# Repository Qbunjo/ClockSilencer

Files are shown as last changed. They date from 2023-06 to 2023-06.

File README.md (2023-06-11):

# ClockSilencer
ClockSilencer is a simple ESP32 device. It plays recorded chime on certain hours.
## Why do I need that?
The problem is, I've got an antique pendulum clock from 1930s. When it chimes, it chimes all day long, day and night. I just wanted to silence it at night.
My first idea was to build a blocking mechanism inside the clock box, but it turns out to be very difficult and I had some doubts about the clock mechanism.
Much more elegant solution is having another electronic clock, that plays recorded chime on certain hours.

## Hardware:
- ESP32 WROOM
- DFPlayer mini
- micro SD card (a small one will be enough - 8gb or even less)
- MOSFET transistor (it turns out that DFPlayer is power-hungry even if it sleeps, so it's better to cut its power)
- DS3231 RTC 
### Why not use ESP32's internal RTC?
Because it turns out, when in deepsleep, internal RTC becomes inacurrate (like 5 minutes in 12 hours)

## Libraries:
- RTClib - runs DS3231 clock
- HardwareSerial - as DFPlayer is driven by Serial port, second serial must be set.
- DFPlayerMini_Fast - driver for DFPlayer Mini, but not from DFRobot :)
- FireTimer (dependency of DFPlayer library)

## Wiring:
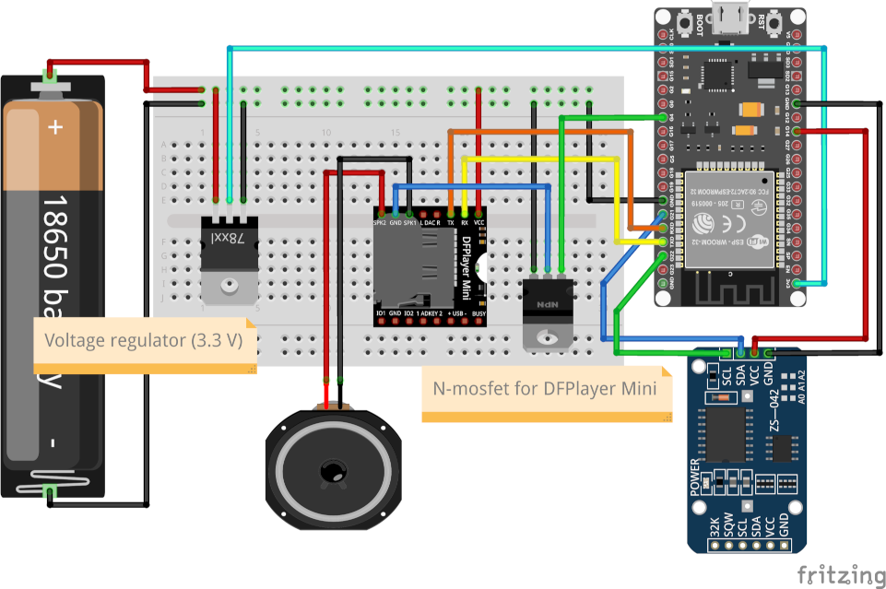
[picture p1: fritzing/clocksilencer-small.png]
Fritzing ESP32 schema


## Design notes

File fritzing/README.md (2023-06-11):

# Fritzing

## Fritzing parts

Please open the parts in this folder to add them into your Fritzing library:

1. [18650 Battery Holder](https://forum.fritzing.org/t/18650-battery-holder-part-design/6523/24)
    - `18650 battery holder_mod.fzpz`
2. [ESP32 Wroom-32U](https://forum.fritzing.org/t/esp32-wroom-32u/12978/2)
    - `ESP32-38PinWide-fixed.fzpz`
3. [DFPlayer Mini](https://fritzing.org/projects/dfplayer-mini-part)
    - `DFPlayer MINI.fzpz`

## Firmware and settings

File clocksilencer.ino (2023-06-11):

#include <DFPlayerMini_Fast.h>
#include <HardwareSerial.h>
//#include <ESP32Time.h> //we quit using this crappy internal RTC
#include <WiFi.h>
#include "RTClib.h"

RTC_DS3231 rtc;
HardwareSerial hwSerial(1);
DFPlayerMini_Fast myDFPlayer;
char daysOfTheWeek[7][12] = { "Sunday", "Monday", "Tuesday", "Wednesday", "Thursday", "Friday", "Saturday" };
const char *ssid = "SSID";
const char *password = "PASS";
RTC_DATA_ATTR bool rtcTimeWasAlreadySetFromNTP = false;
bool noWifi;
int myDow, mySec, myMin, myHour;
int sleepHelper;

void setup() {
  pinMode(4, OUTPUT);
  pinMode(14,OUTPUT);
  //digitalWrite(14, HIGH);//give power to rtc
  Serial.begin(115200);
  hwSerial.begin(9600, SERIAL_8N1, 16, 17);  // second serial port to serve mp3 player
  
  if (rtcTimeWasAlreadySetFromNTP == false) {
    synchroniseExternalTime();
  }
}

void loop() {
  //---this is serial output to make sure we have correct time
  //DateTime now = rtc.now();
  DateTime now =grabTime();
  
  //--- here are regular conditions
  myDow = now.dayOfTheWeek();
  mySec = now.second();
  myMin = now.minute();
  myHour = now.hour();
Serial.print("It is ");
Serial.print(myHour);
Serial.print(":");
Serial.print(myMin);
Serial.print(":");
Serial.println(mySec);


  if (myMin > 31) {
    sleepHelper = 59 - myMin;
  } else {
    sleepHelper = 29 - myMin;
  };
  if (myHour > 7 and myHour < 19 and mySec == 55 and sleepHelper == 0) {  //according to the DFPlayer documentation, it needs 3-5 seconds to start
    startPlayer();
  }

  //---------ringing conditions----------

  if (mySec == 0 and myMin == 0) {     // at full hour
    if (myHour > 7 and myHour < 19) {  // between 8 and 18
      // here another condition
      ringer(myHour);
    }
  }
  if (mySec == 0 and myMin == 30) {    // at half hour
    if (myHour > 7 and myHour < 19) {  // between 8 and 18
      // here another condition
      ringer(1);
    }
  }


  // -----deep sleep conditions--------
  if ((sleepHelper > 2)) {
    deepsleep(sleepHelper);
  }
  delay(1000);  //if there is a short time to chime, just work with delay
}
void ringer(int myhours2) {
  //run mosfet here

  Serial.print("Ringing:");
  Serial.println(myhours2);
  if (myhours2 > 12) {
    myhours2 -= 12;
  }
  for (int n = 1; n <= myhours2; n++) {
    Serial.print("Ring nr:");
    Serial.println(n);
    if (n == 1) {
      myDFPlayer.playFromMP3Folder(1);
      delay(2250);

    }  // ring the chime
    else {
      myDFPlayer.playFromMP3Folder(2);
      delay(2250);
    }
  }
  while (myDFPlayer.isPlaying()) {
  };
  digitalWrite(4, LOW);
  Serial.println("Mosfet low");

}
void deepsleep(int sleepHelper) {
  int countMicro = ((sleepHelper - 1) * 1000000 * 60);
  esp_sleep_enable_timer_wakeup(countMicro);
  Serial.println("Deepsleep");
  Serial.print("Wake up in ");
  Serial.print(sleepHelper);
  Serial.print(" minutes, at ");
  Serial.print(myHour);
  Serial.print(":");
  Serial.println(myMin += sleepHelper);
  esp_deep_sleep_start();
}
void synchroniseExternalTime() {
  WiFi.begin(ssid, password);
  Serial.println("Looking for the WiFi");
  while (WiFi.status() != WL_CONNECTED) {
    delay(500);
    Serial.print(".");
    // if wifi found, break loop
  }
  Serial.println("WiFi connected");
  //---------set with NTP---------------
  // we have to rebuild this function to synchronise ext rtc
  configTime(3600, 3600, "europe.pool.ntp.org");
  //==== //this need to be further modified to meet the requirements of RTClib
  struct tm timeinfo;
  getLocalTime(&timeinfo);

  int yr = timeinfo.tm_year + 1900;
  int mt = timeinfo.tm_mon + 1;
  int dy = timeinfo.tm_mday;
  int hr = timeinfo.tm_hour;
  int mi = timeinfo.tm_min;
  int se = timeinfo.tm_sec;

  digitalWrite(14,HIGH);
  rtc.begin();
  rtc.adjust(DateTime(yr, mt, dy, hr, mi, se));

  Serial.println("RTC updated");
  DateTime now = rtc.now();
  Serial.print("It is ");
  Serial.print(now.year(), DEC);
  Serial.print('/');
  Serial.print(now.month(), DEC);
  Serial.print('/');
  Serial.print(now.day(), DEC);
  Serial.print(' ');
  Serial.print(now.hour(), DEC);
  Serial.print(':');
  Serial.print(now.minute(), DEC);
  Serial.print(':');
  Serial.print(now.second(), DEC);
  Serial.println();

  WiFi.disconnect();
  WiFi.mode(WIFI_OFF);                 // disconnect after synchronisation to save power
  rtcTimeWasAlreadySetFromNTP = true;  // time was updated
  Serial.println("WiFi turned off");
  digitalWrite(14,LOW); //turn off power for RTC
}

void startPlayer() {
  digitalWrite(4, HIGH);
  Serial.println("Mosfet high");

  hwSerial.begin(9600, SERIAL_8N1, 16, 17);
  Serial.println("Hardware Serial started");
  delay(100);
  while (!myDFPlayer.begin(hwSerial)) {

  };  //initializing mp3 player
  myDFPlayer.volume(25);
  delay(10);
}

DateTime grabTime(){
  digitalWrite(14,HIGH);
  while (!rtc.begin()) {
    Serial.println("Couldn't find RTC");
      delay(10);
  }
  DateTime now = rtc.now();
  digitalWrite(14,LOW);
  return now;
}

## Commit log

2022-10-04 Version 2.0
    Clock chime for ESP32.
    Works on RTC clock
2023-05-11 Added deepsleep
    Added deepsleep in order to save battery.
    Addes sleep to DFPlayer also.
2023-05-14 Update clocksilencer.ino
    added boolean and few improvements (but not working yet :) )
    [clocksilencer.ino]
2023-05-17 added destructor and mosfet driver
2023-05-23 Update README.md
    added mosfet
2023-06-02 Working version with external RTC
    DS3231 connected to I2C bus on pins 21 and 22
2023-06-04 Adding power driving to rtc
2023-06-11 improved battery save procedures
2023-06-11 initial version of fritzing image for hardware
    [clocksilencer.fzz]
2023-06-11 remove not needed note
    [clocksilencer.fzz]
2023-06-11 Fritzing comment update
    [clocksilencer.fzz]
2023-06-11 fix for DFPlayer mini shifted
    [clocksilencer.fzz]
2023-06-11 switch image in main README file
2023-06-11 Add rtc clock
    [clocksilencer.fzz]
2023-06-11 Reorganize wires
    [clocksilencer.fzz]
